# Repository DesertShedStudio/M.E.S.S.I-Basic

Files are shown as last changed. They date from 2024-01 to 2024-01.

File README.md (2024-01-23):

M.E.S.S.I Basic
============

The "M.E.S.S.I Basic" is an open source OSHWA Certified hardware design, implementing a RS-422 interface for use with Mesa Ethernet Anything 
I/O Cards and Mesa Electronics smart serial daughter cards.

M.E.S.S.I <br>
"Mesa Electronics Smart Serial Interface"



This repository is aimed towards those who wish to manufacture their own boards. 

Board Rendering
============

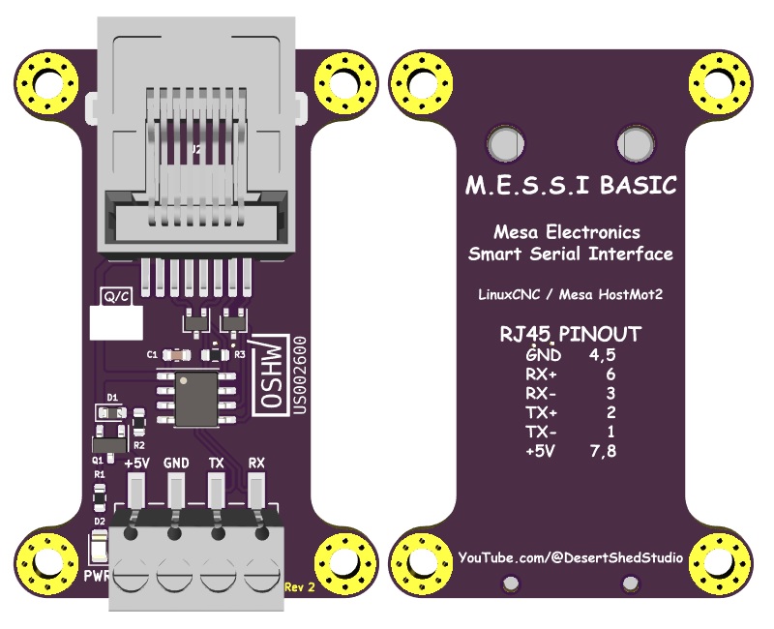
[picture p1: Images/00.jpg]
M.E.S.S.I Basic Rendering


License
=======

M.E.S.S.I Basic | https://github.com/DesertShedStudio/M.E.S.S.I-Basic <br>
Copyright (c) Desert Shed Studio

This source describes Open Hardware and is licensed under the CERN-OHL-S v2.

You may redistribute and modify this source and make products using it under <br>
the terms of the CERN-OHL-S v2 (https://ohwr.org/cern_ohl_s_v2.txt). <br>

This source is distributed WITHOUT ANY EXPRESS OR IMPLIED WARRANTY, <br>
INCLUDING OF MERCHANTABILITY, SATISFACTORY QUALITY AND FITNESS FOR A <br>
PARTICULAR PURPOSE. Please see the CERN-OHL-S v2 for applicable conditions.

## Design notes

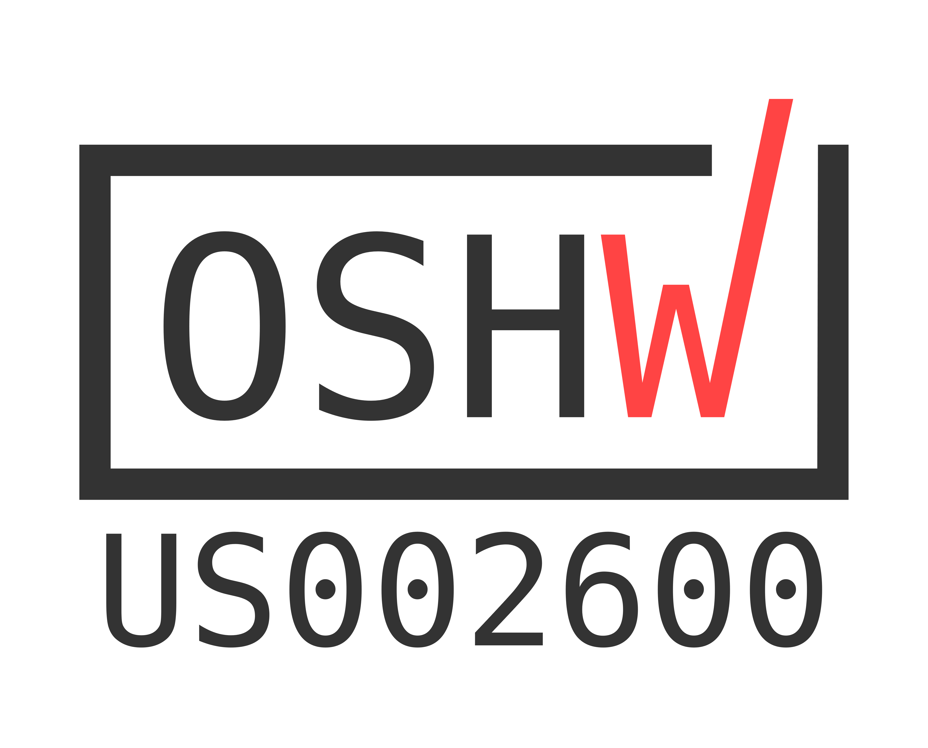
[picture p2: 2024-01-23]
Images/certification-mark-US002600-stacked.png

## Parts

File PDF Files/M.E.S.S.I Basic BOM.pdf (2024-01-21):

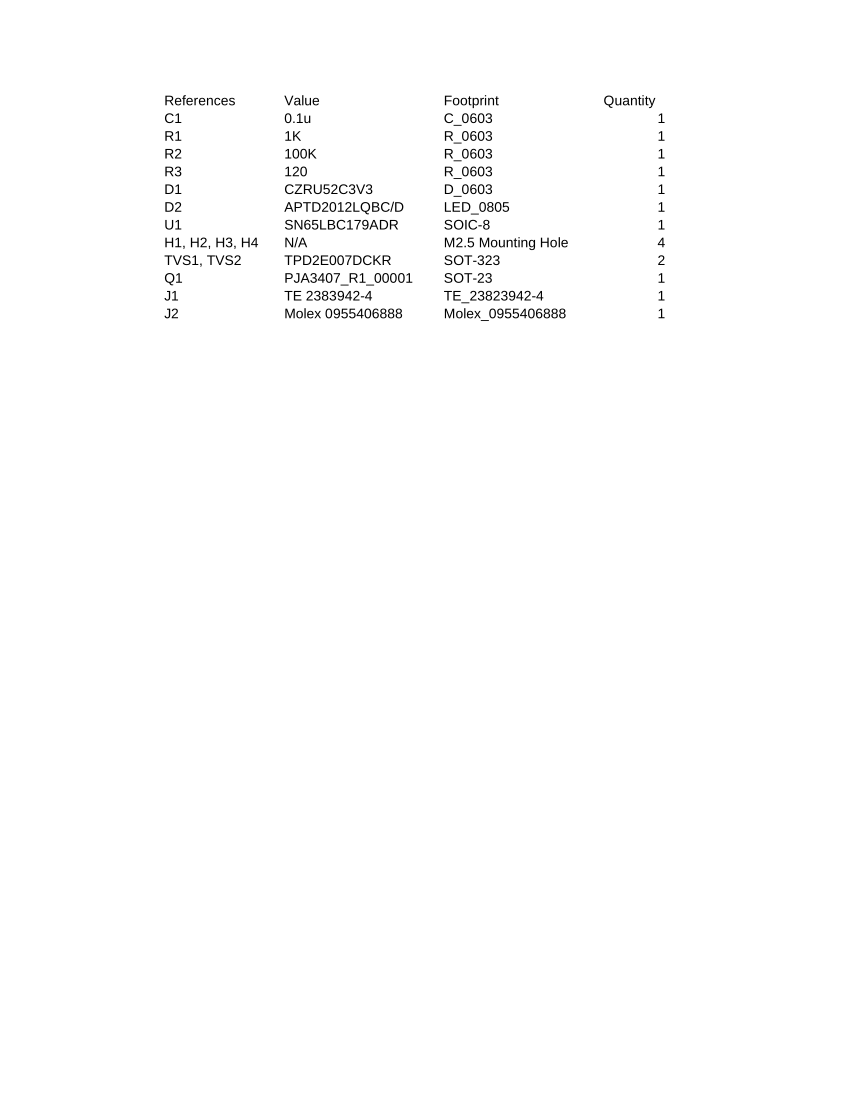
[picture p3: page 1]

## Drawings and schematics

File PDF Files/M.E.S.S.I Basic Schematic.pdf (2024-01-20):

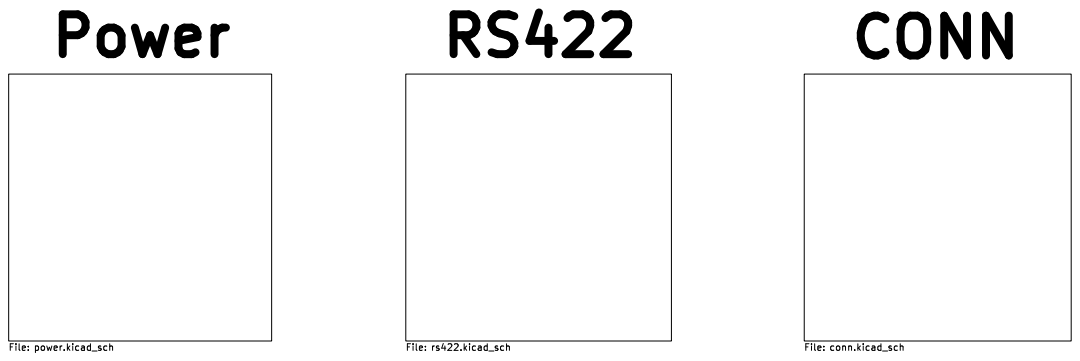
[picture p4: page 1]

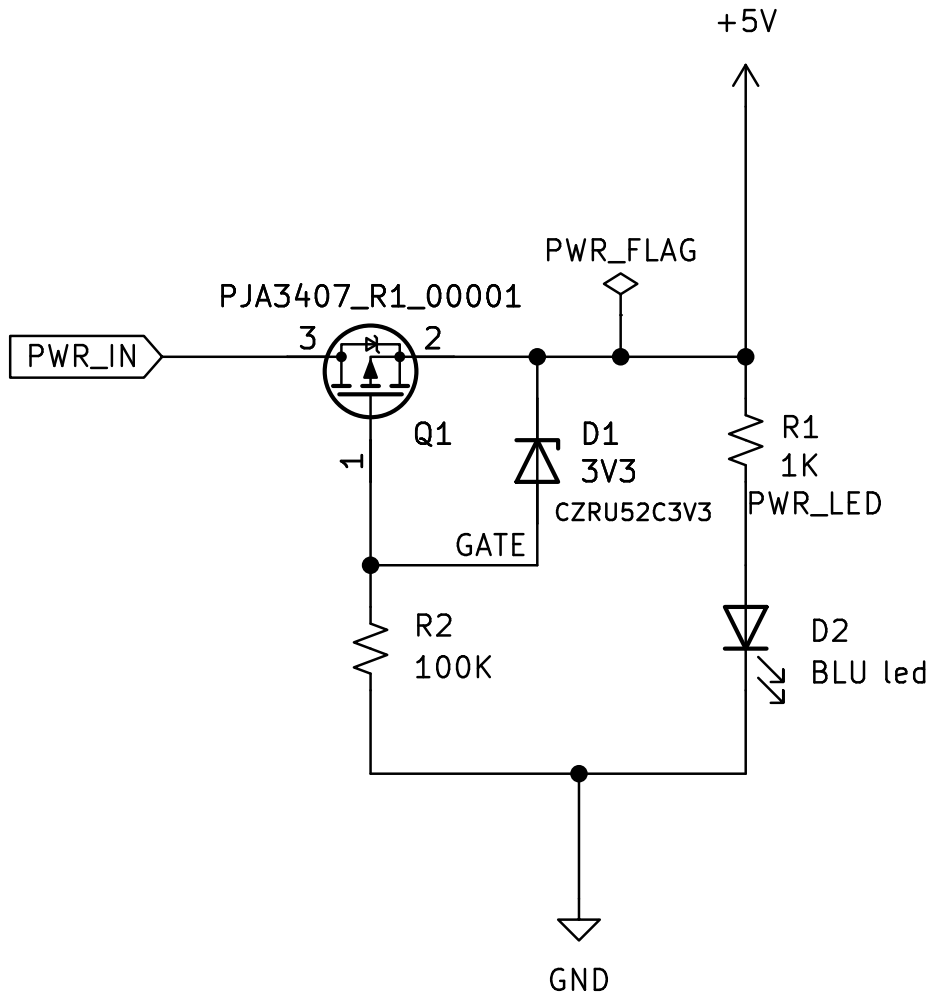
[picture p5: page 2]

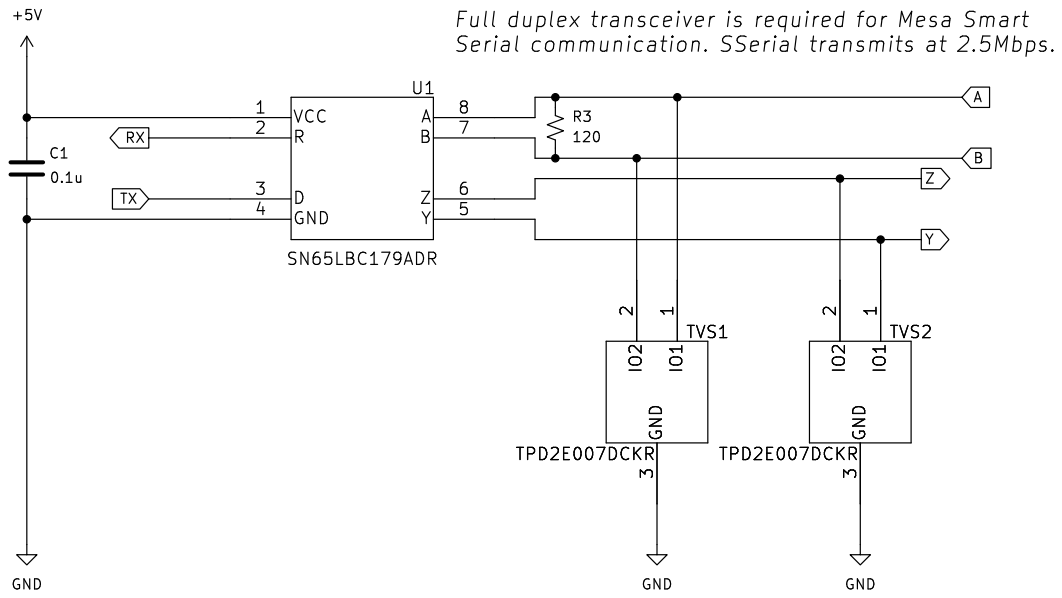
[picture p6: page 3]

Y Full duplex transceiver is required for Mesa Smart

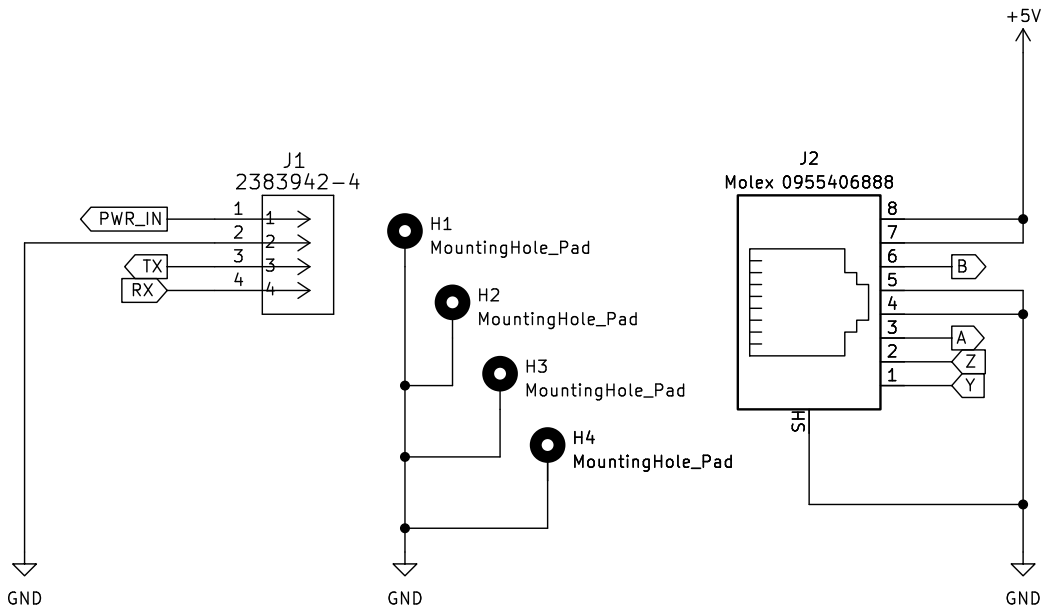
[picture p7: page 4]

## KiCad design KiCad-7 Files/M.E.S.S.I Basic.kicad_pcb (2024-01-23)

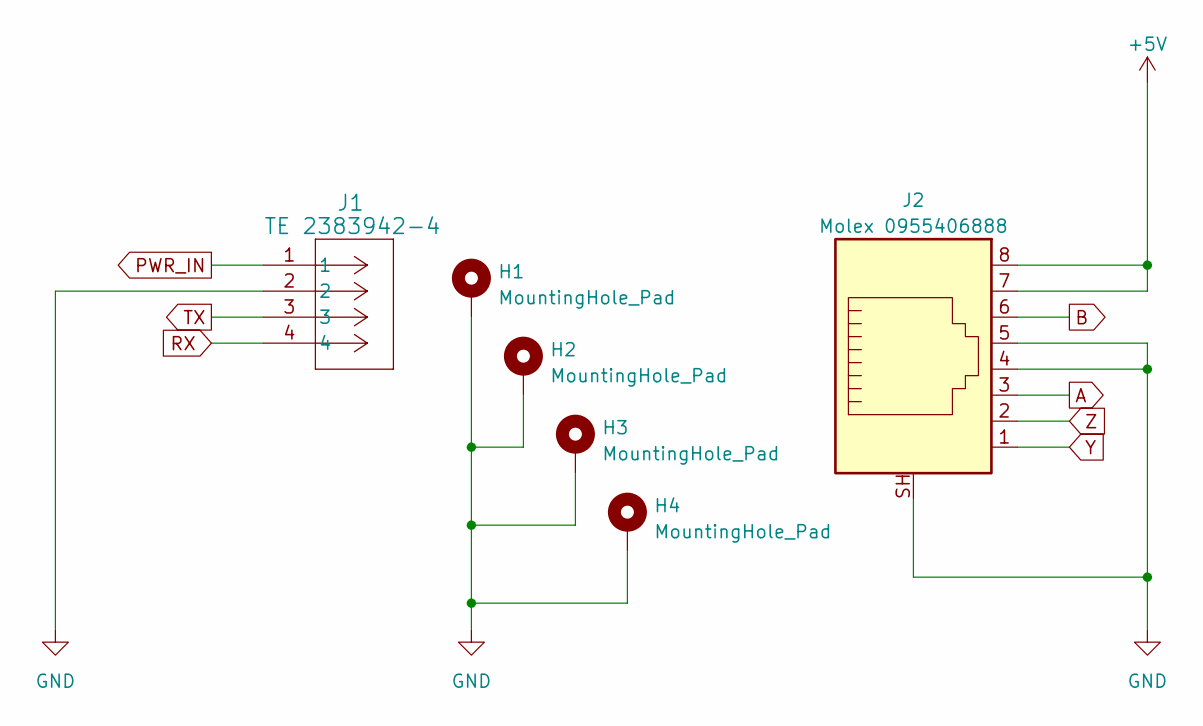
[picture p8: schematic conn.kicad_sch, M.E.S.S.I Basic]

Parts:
H1, H2, H3, H4: MountingHole_Pad; MountingHole_2.7mm_M2.5_Pad_Via
J1: TE 2383942-4; TE_23823942-4
J2: Molex 0955406888; Molex_0955406888

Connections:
+5V: J2.7, J2.8; also elsewhere on the board
A: J2.3; also elsewhere on the board
B: J2.6; also elsewhere on the board
GND: H1.1, H2.1, H3.1, H4.1, J1.2, J2.4, J2.5, J2.SH; also elsewhere on the board
PWR_IN: J1.1; also elsewhere on the board
RX: J1.4; also elsewhere on the board
TX: J1.3; also elsewhere on the board
Y: J2.1; also elsewhere on the board
Z: J2.2; also elsewhere on the board

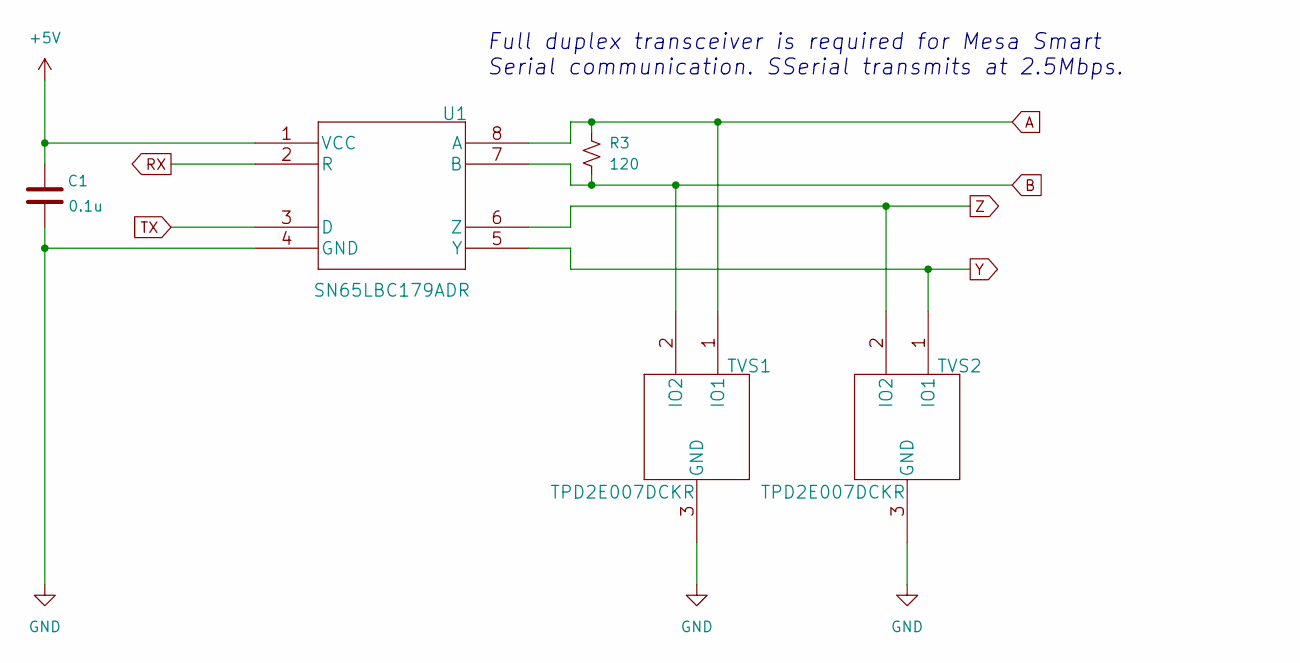
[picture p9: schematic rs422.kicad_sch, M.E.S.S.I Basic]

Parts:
C1: 0.1u; C_0603_1608Metric
R3: 120; R_0603_1608Metric
TVS1, TVS2: TPD2E007DCKR; SOT-323_SC-70
U1: SN65LBC179ADR; SOIC-8_3.9x4.9mm_P1.27mm

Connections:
+5V: C1.2, U1.1 (VCC); also elsewhere on the board
A: R3.1, TVS1.1 (IO1), U1.8 (A); also elsewhere on the board
B: R3.2, TVS1.2 (IO2), U1.7 (B); also elsewhere on the board
GND: C1.1, TVS1.3 (GND), TVS2.3 (GND), U1.4 (GND); also elsewhere on the board
RX: U1.2 (R); also elsewhere on the board
TX: U1.3 (D); also elsewhere on the board
Y: TVS2.1 (IO1), U1.5 (Y); also elsewhere on the board
Z: TVS2.2 (IO2), U1.6 (Z); also elsewhere on the board

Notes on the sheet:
Full duplex transceiver is required for Mesa Smart Serial communication. SSerial transmits at 2.5Mbps.

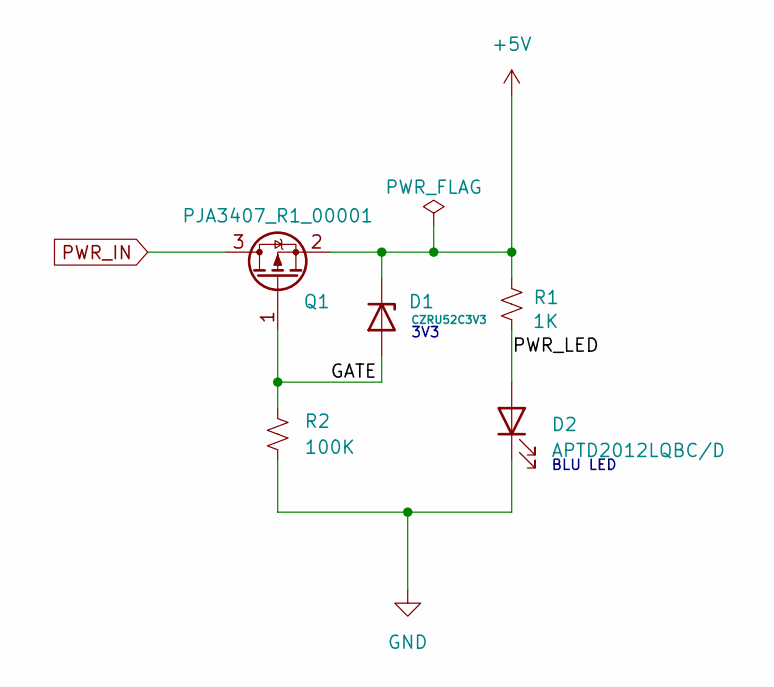
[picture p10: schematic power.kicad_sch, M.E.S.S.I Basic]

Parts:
D1: CZRU52C3V3; D_0603_1608Metric
D2: APTD2012LQBC/D; LED_0805_2012Metric
Q1: PJA3407_R1_00001; SOT-23
R1: 1K; R_0603_1608Metric
R2: 100K; R_0603_1608Metric

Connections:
+5V: D1.1 (K), Q1.2 (S), R1.1; also elsewhere on the board
/Power/GATE: D1.2 (A), Q1.1 (G), R2.1
/Power/PWR_LED: D2.2 (A), R1.2
GND: D2.1 (K), R2.2; also elsewhere on the board
PWR_IN: Q1.3 (D); also elsewhere on the board

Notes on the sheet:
3V3
BLU LED

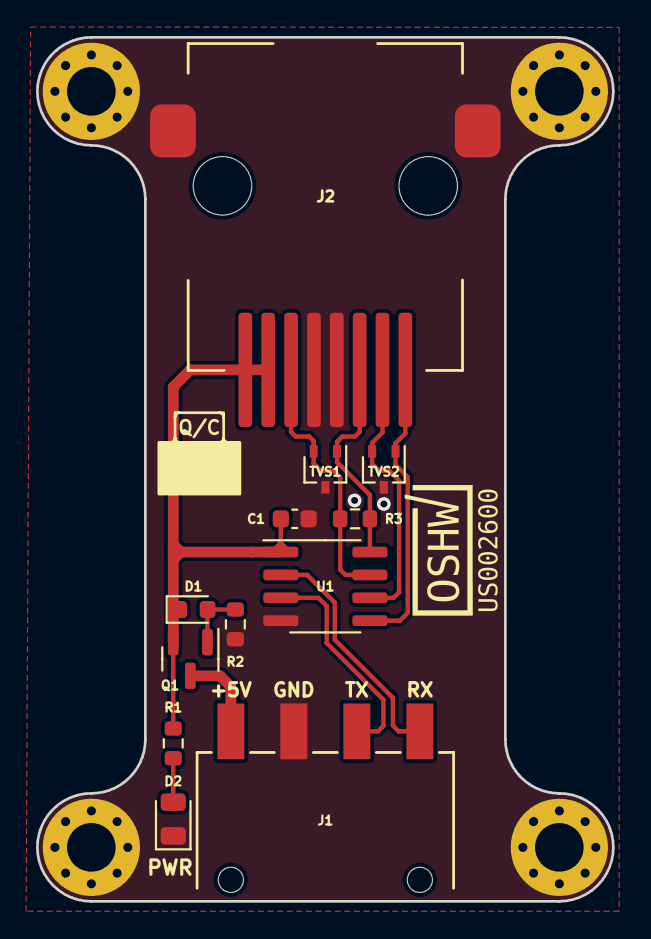
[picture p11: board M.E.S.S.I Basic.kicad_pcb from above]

Board: 2 copper layers, 32.0 x 48.0 mm, 16 parts (0 on the bottom side), 11 nets.

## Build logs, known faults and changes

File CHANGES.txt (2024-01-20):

Anyone modifying this design should provide brief information about the
modifications, including the date they were made.

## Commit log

2024-01-20 Add files via upload
    Initial upload of M.E.S.S.I Basic source files.
    [M.E.S.S.I Basic-B_Cu.gbr, M.E.S.S.I Basic-B_Mask.gbr, M.E.S.S.I Basic-B_Paste.gbr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]
2024-01-20 Update README.md
    Fixed board rendering url.
2024-01-20 Update README.md
    fixed board rendering url formatting.
2024-01-21 Rename M.E.S.S.I Basic.pdf to M.E.S.S.I Basic Schematic.pdf
    Updated name to reflect file contents.
2024-01-21 Add files via upload
    Added pdf file for BOM.
2024-01-23 Add files via upload
    upload new gerbers with certification mark.
    [M.E.S.S.I Basic-B_Cu.gbr, M.E.S.S.I Basic-B_Mask.gbr, M.E.S.S.I Basic-B_Paste.gbr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]
2024-01-23 Add files via upload
    upload new kicad 7 files with certification mark
    [M.E.S.S.I Basic.kicad_pcb, conn.kicad_sch, power.kicad_sch]
